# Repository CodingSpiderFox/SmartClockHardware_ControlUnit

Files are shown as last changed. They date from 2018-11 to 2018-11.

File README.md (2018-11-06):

# SmartClockHardware (ControlUnit)

This is part of the the hardware specification for my smart clock project.

The hardware consists of one device for the wake-up light functionality and another for the controls and LCD display.

The control unit with the display again, consists of 3 major parts held in one encasing

1.1) The controller for the input devices: various buttons and a PIR motion sensor.
There are many buttons for quite a lot of different features. As the NodeMCU doesn't have enough pins, two PCF8574 IO expander chips are used (yes, I tried the MCP23017 but didn't like the libraries and didn't want to write a new one).

1.2) The Mega2560 devboard with a 2.8" touch display shield on it and the two other parts (1.1 and 1.3) connected via hardware serials.

1.3) The NodeMCU controlling the illuminated button's lights.
Two buttons have RGB leds in the which can be controlled separately.
The other 9 buttons have single colour LEDs. All of the button's LEDs can be adjusted to different brightness levels, together with the LCD panel's backlight brightness.

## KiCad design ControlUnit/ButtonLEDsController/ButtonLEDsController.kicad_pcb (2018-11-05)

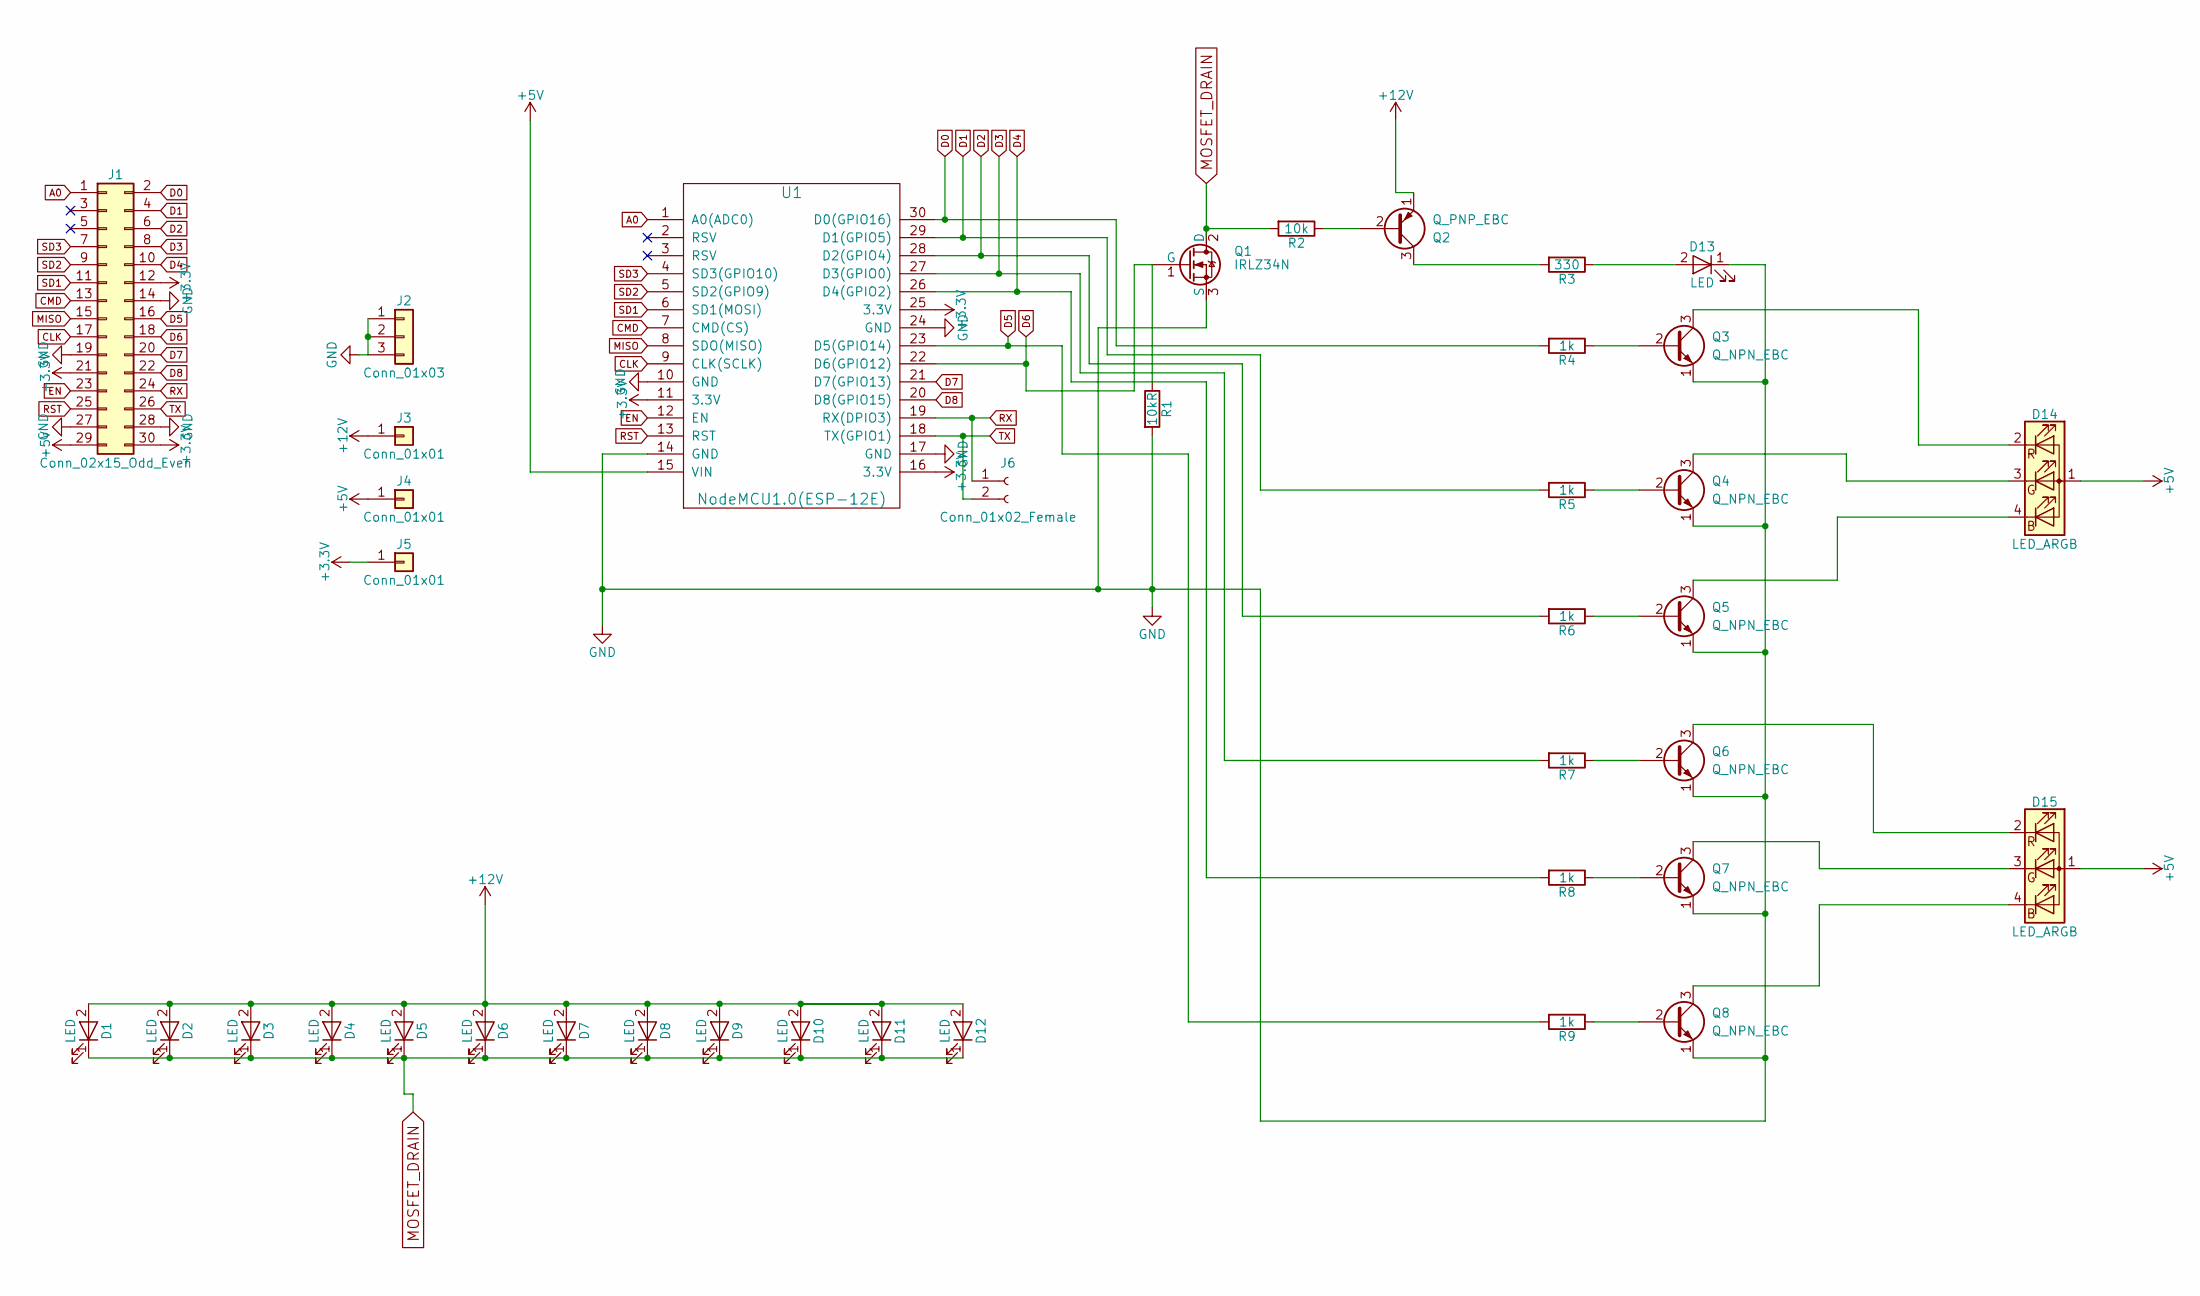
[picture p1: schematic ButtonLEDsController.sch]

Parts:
D1, D2, D3, D4, D5, D6, D7, D8, D9, D10, D11, D12, D13: LED; LED_D5.0mm
D14, D15: LED_ARGB; Pin_Header_Straight_1x04
J1: Conn_02x15_Odd_Even; Pin_Header_Straight_2x15_Pitch2.54mm
J2: Conn_01x03; Pin_Header_Straight_1x03_Pitch2.54mm
J3, J4, J5: Conn_01x01; Pin_Header_Straight_1x01_Pitch2.54mm
J6: Conn_01x02_Female; Socket_Strip_Straight_1x02_Pitch2.54mm
Q1: IRLZ34N; TO-220
Q2: Q_PNP_EBC; TO-92_Molded_Narrow
Q3, Q4, Q5, Q6, Q7, Q8: Q_NPN_EBC; TO-92_Molded_Narrow
R1: 10kR; R_Axial_DIN0204_L3.6mm_D1.6mm_P7.62mm_Horizontal
R2: 10k; R_Axial_DIN0204_L3.6mm_D1.6mm_P7.62mm_Horizontal
R3: 330; R_Axial_DIN0204_L3.6mm_D1.6mm_P7.62mm_Horizontal
R4, R5, R6, R7, R8, R9: 1k; R_Axial_DIN0204_L3.6mm_D1.6mm_P7.62mm_Horizontal
U1: NodeMCU1.0(ESP-12E); NodeMCU1.0(12-E)

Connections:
+3V3: J1.12, J1.21, J1.30, J5.1, U1.11 (3.3V), U1.16 (3.3V), U1.25 (3.3V)
+5V: D14.1 (A), D15.1 (A), J1.29, J4.1, U1.15 (VIN)
+12V: D1.2 (A), D2.2 (A), D3.2 (A), D4.2 (A), D5.2 (A), D6.2 (A), D7.2 (A), D8.2 (A), D9.2 (A), D10.2 (A), D11.2 (A), D12.2 (A), J3.1, Q2.1 (E)
A0: J1.1, U1.1 (A0(ADC0))
CLK: J1.17, U1.9 (CLK(SCLK))
CMD: J1.13, U1.7 (CMD(CS))
D0: J1.2, R4.2, U1.30 (D0(GPIO16))
D1: J1.4, R5.2, U1.29 (D1(GPIO5))
D2: J1.6, R6.2, U1.28 (D2(GPIO4))
D3: J1.8, R7.2, U1.27 (D3(GPIO0))
D4: J1.10, R8.2, U1.26 (D4(GPIO2))
D5: J1.16, R9.2, U1.23 (D5(GPIO14))
D6: J1.18, Q1.1 (G), R1.1, U1.22 (D6(GPIO12))
D7: J1.20, U1.21 (D7(GPIO13))
D8: J1.22, U1.20 (D8(GPIO15))
EN: J1.23, U1.12 (EN)
GND: D13.1 (K), J1.14, J1.19, J1.27, J1.28, J2.1, J2.2, J2.3, Q1.3 (S), Q3.1 (E), Q4.1 (E), Q5.1 (E), Q6.1 (E), Q7.1 (E), Q8.1 (E), R1.2, U1.10 (GND), U1.14 (GND), U1.17 (GND), U1.24 (GND)
MISO: J1.15, U1.8 (SDO(MISO))
MOSFET_DRAIN: D1.1 (K), D2.1 (K), D3.1 (K), D4.1 (K), D5.1 (K), D6.1 (K), D7.1 (K), D8.1 (K), D9.1 (K), D10.1 (K), D11.1 (K), D12.1 (K), Q1.2 (D), R2.2
unnamed: D13.2 (A), R3.1
unnamed: D14.2 (RK), Q3.3 (C)
unnamed: D14.3 (GK), Q4.3 (C)
unnamed: D14.4 (BK), Q5.3 (C)
unnamed: D15.2 (RK), Q6.3 (C)
unnamed: D15.3 (GK), Q7.3 (C)
unnamed: D15.4 (BK), Q8.3 (C)
unnamed: Q2.2 (B), R2.1
unnamed: Q2.3 (C), R3.2
unnamed: Q3.2 (B), R4.1
unnamed: Q4.2 (B), R5.1
unnamed: Q5.2 (B), R6.1
unnamed: Q6.2 (B), R7.1
unnamed: Q7.2 (B), R8.1
unnamed: Q8.2 (B), R9.1
RST: J1.25, U1.13 (RST)
RX: J1.24, J6.1, U1.19 (RX(DPIO3))
SD1: J1.11, U1.6 (SD1(MOSI))
SD2: J1.9, U1.5 (SD2(GPIO9))
SD3: J1.7, U1.4 (SD3(GPIO10))
TX: J1.26, J6.2, U1.18 (TX(GPIO1))

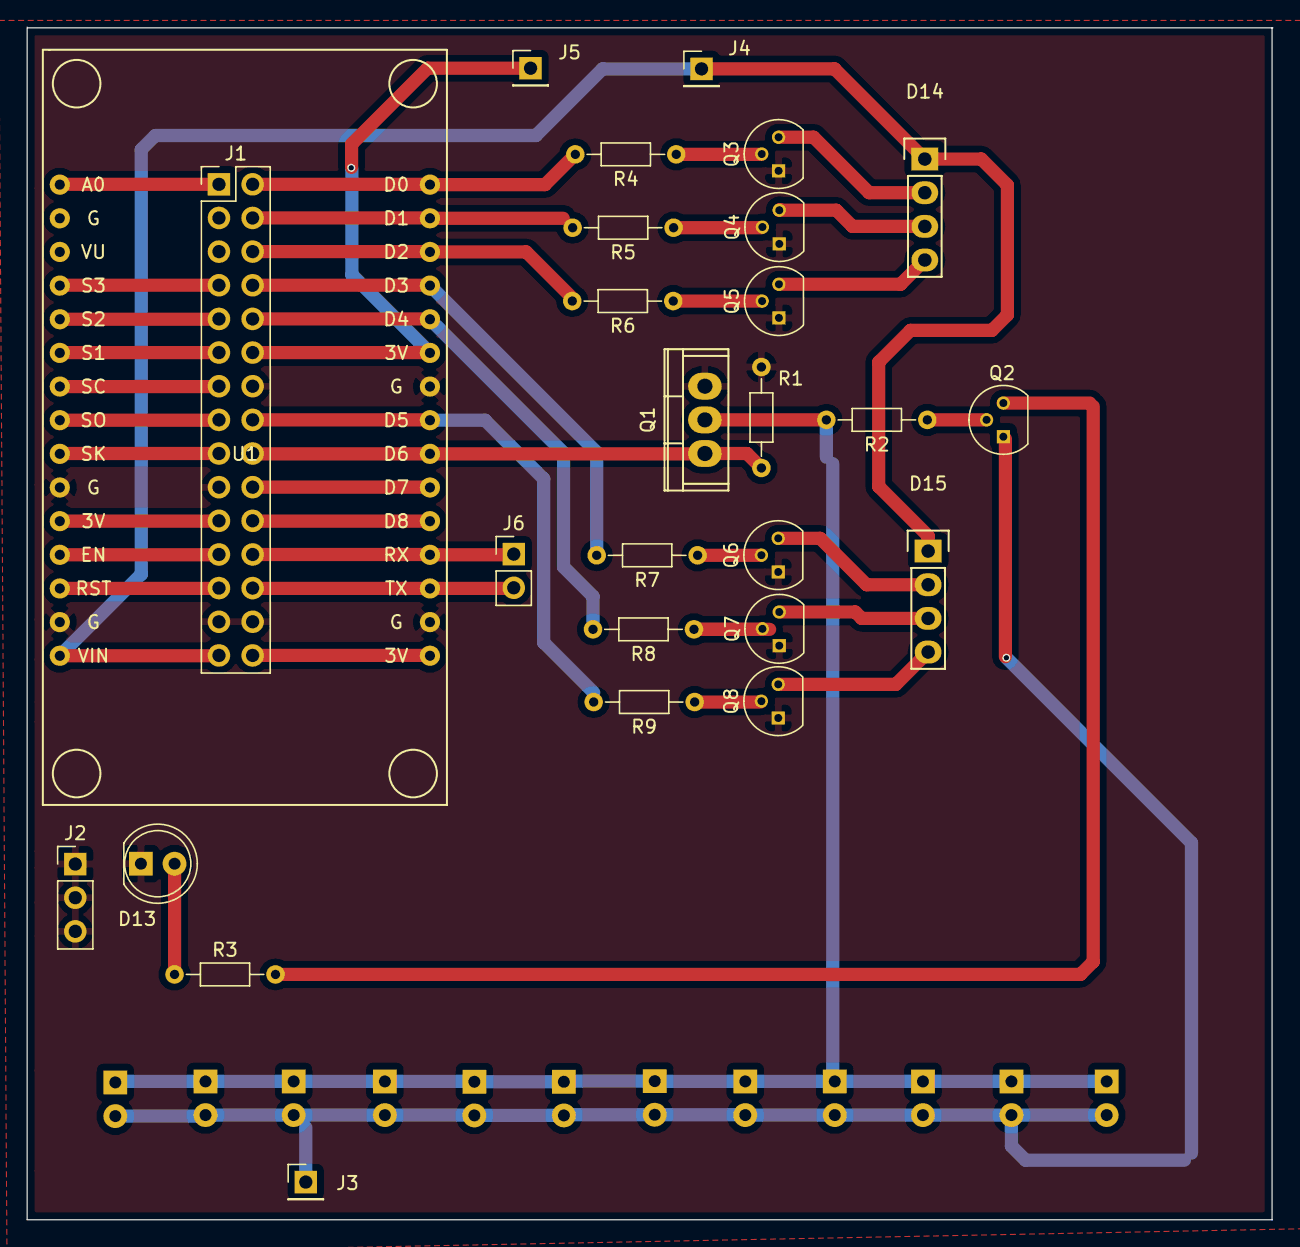
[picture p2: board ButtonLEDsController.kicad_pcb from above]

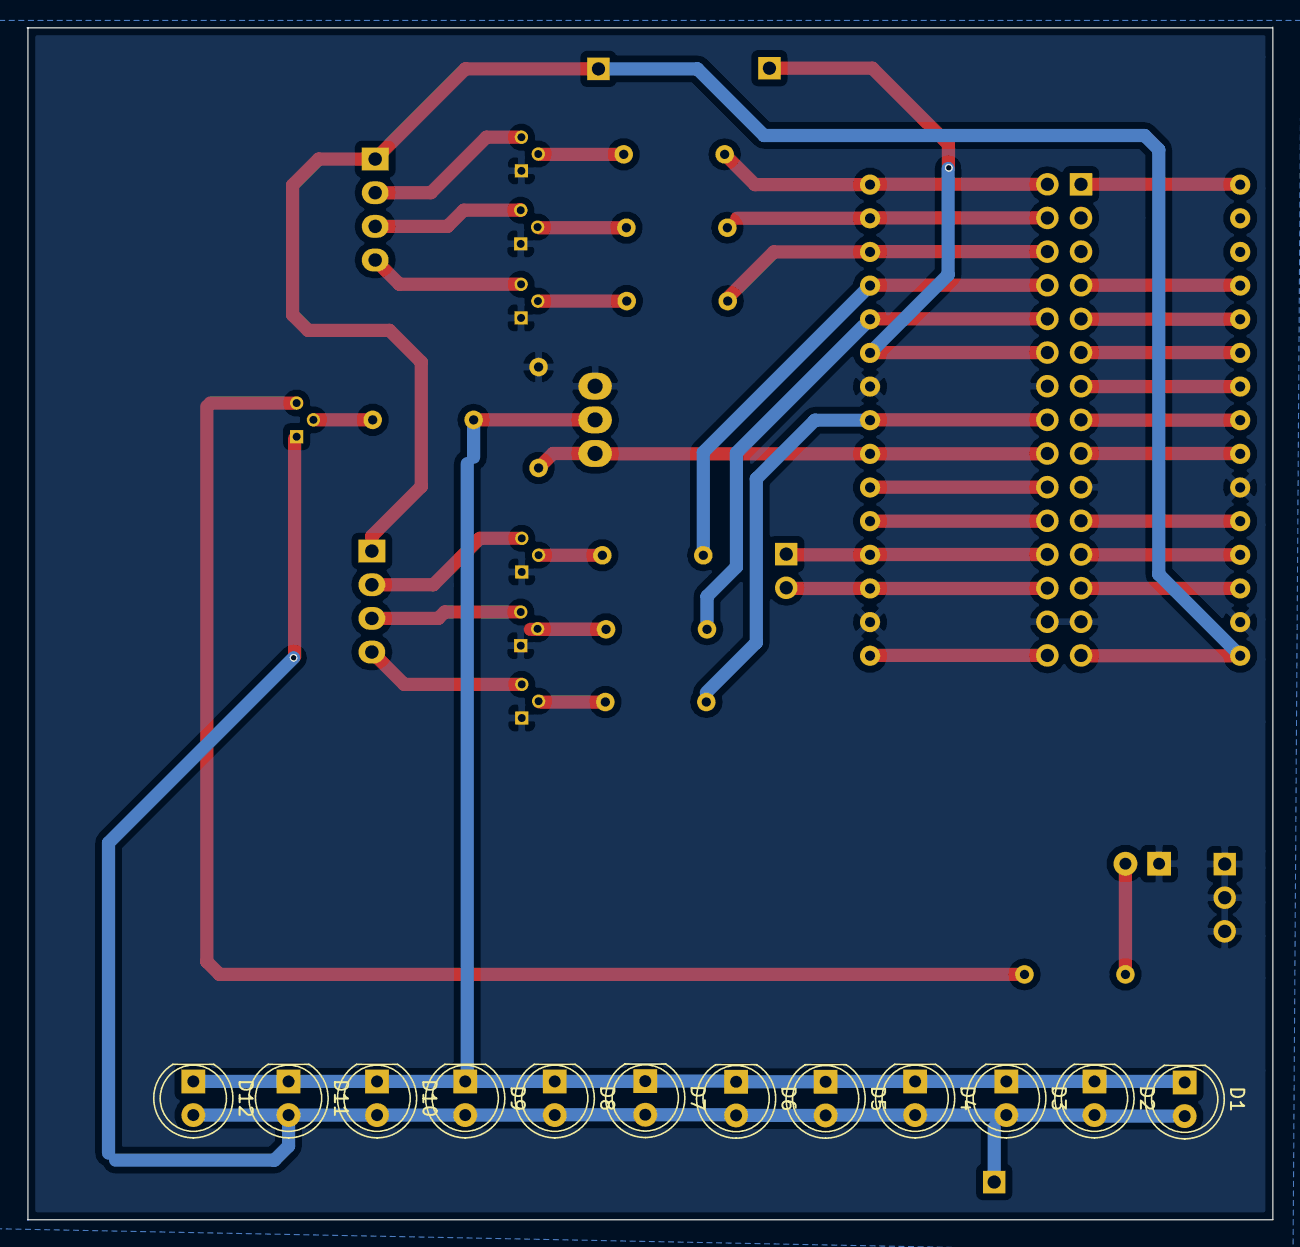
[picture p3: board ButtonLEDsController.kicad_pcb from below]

Board: 2 copper layers, 94.0 x 90.0 mm, 39 parts (12 on the bottom side), 40 nets.

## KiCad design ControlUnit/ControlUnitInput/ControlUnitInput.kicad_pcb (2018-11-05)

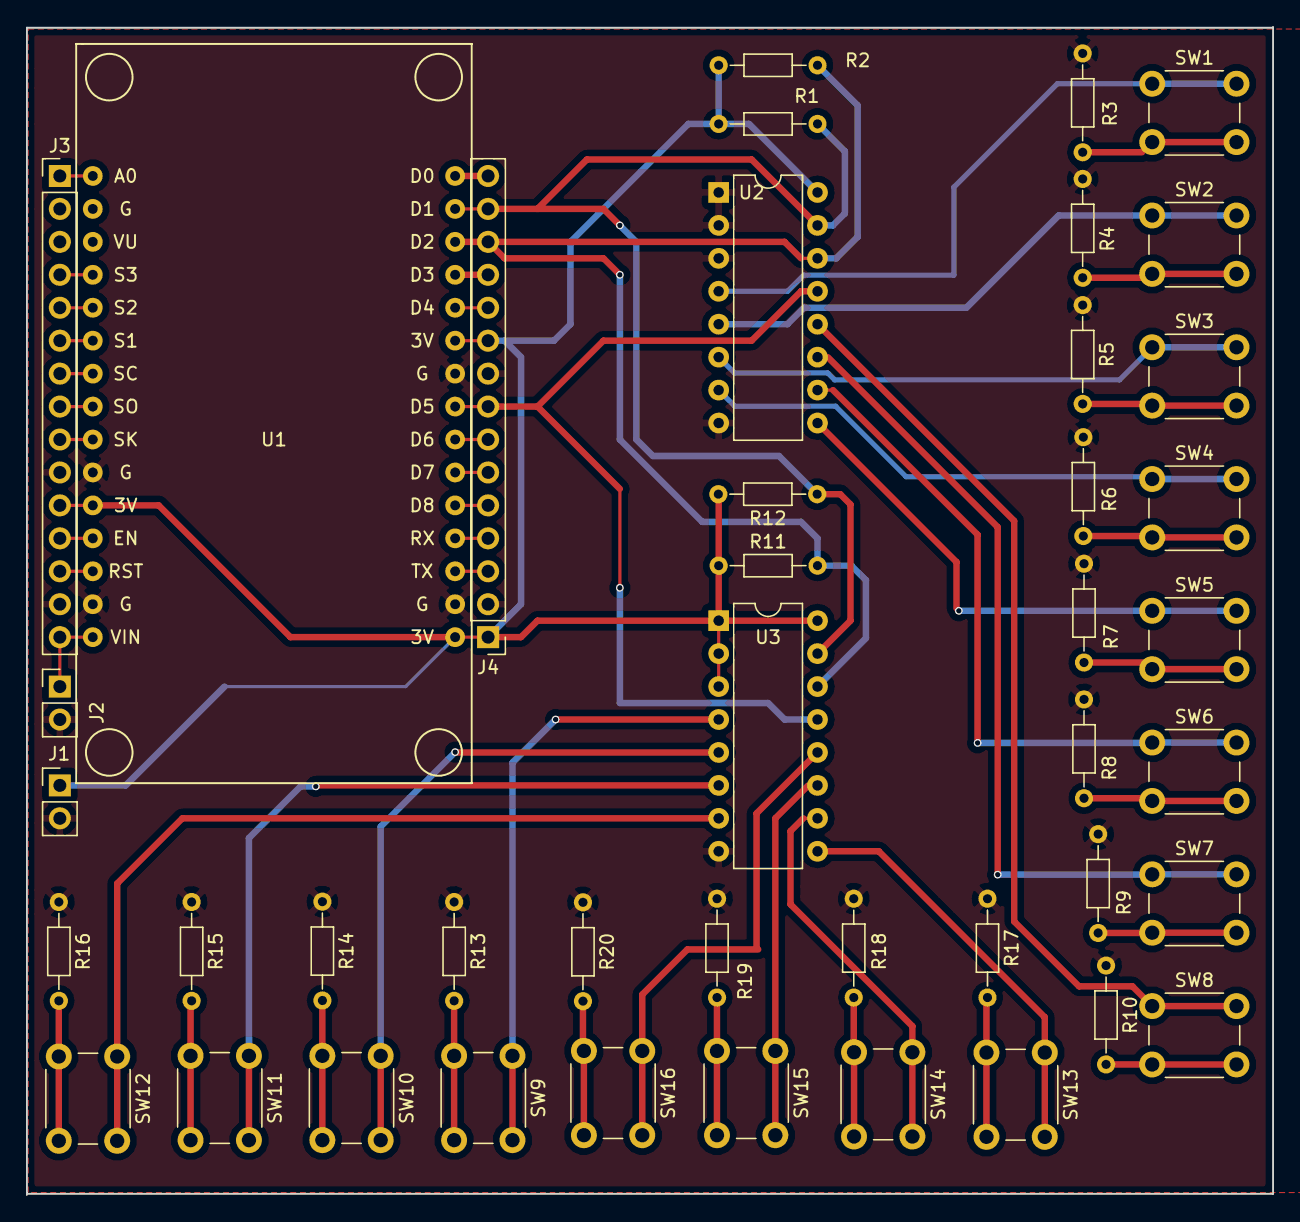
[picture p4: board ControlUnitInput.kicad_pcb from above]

Board: 2 copper layers, 96.1 x 90.1 mm, 43 parts (0 on the bottom side), 55 nets.

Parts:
J1, J2: Pin_Header_Straight_1x02_Pitch2.54mm
J3, J4: Pin_Header_Straight_1x15_Pitch2.54mm
R1, R2, R11, R12: 4.7k; R_Axial_DIN0204_L3.6mm_D1.6mm_P7.62mm_Horizontal
R3, R4, R5, R6, R7, R8, R9, R10, R13, R14, R15, R16, R17, R18, R19, R20: 10k; R_Axial_DIN0204_L3.6mm_D1.6mm_P7.62mm_Horizontal
SW1, SW2, SW3, SW4, SW5, SW6, SW7, SW8, SW9, SW10, SW11, SW13, SW14, SW15, SW16: SW_Push; SW_PUSH_6mm_h8mm
SW12: SW_PUSH_6mm_h8mm
U1: NodeMCU1.0(ESP-12E); NodeMCU1.0(12-E)
U2: DIP-16_W7.62mm
U3: PCF8574; DIP-16_W7.62mm

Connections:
+3V3: J1.1, J3.11, J4.1, J4.10, R1.2, R2.1, R11.1, R12.2, U1.11, U1.16, U1.25, U2.16, U3.1, U3.2, U3.3, U3.16
+5V: J2.1, J3.15, U1.15
A0: J3.1, U1.1
CLK: J3.9, U1.9
CMD: J3.7, U1.7
D0: J4.15, U1.30
D3: J4.12, U1.27
D4: J4.11, U1.26
D6: J4.7, U1.22
D7: J4.6, U1.21
D8: J4.5, U1.20
EN: J3.12, U1.12
GND: J1.2, J2.2, J3.10, J3.14, J4.2, J4.9, R3.1, R4.1, R5.1, R6.1, R7.1, R8.1, R9.1, R10.1, R13.1, R14.1, R15.1, R16.1, R17.1, R18.1, R19.1, R20.1, U1.10, U1.14, U1.17, U1.24, U2.1, U2.2, U2.3, U2.8, U3.8
INT: J4.8, U1.23, U2.13, U3.13
MISO: J3.8, U1.8
MOSI: J3.6, U1.6
unnamed: R3.2, SW1.2
unnamed: R4.2, SW2.2
unnamed: R5.2, SW3.2
unnamed: R6.2, SW4.2
unnamed: R7.2, SW5.2
unnamed: R8.2, SW6.2
unnamed: R9.2, SW7.2
unnamed: R10.2, SW8.2
unnamed: R13.2, SW9.2
unnamed: R14.2, SW10.2
unnamed: R15.2, SW11.2
unnamed: R16.2, SW12.2
unnamed: R17.2, SW13.2
unnamed: R18.2, SW14.2
unnamed: R19.2, SW15.2
unnamed: R20.2, SW16.2
unnamed: SW1.1, U2.4
unnamed: SW2.1, U2.5
unnamed: SW3.1, U2.6
unnamed: SW4.1, U2.7
unnamed: SW5.1, U2.9
unnamed: SW6.1, U2.10
unnamed: SW7.1, U2.11
unnamed: SW8.1, U2.12
unnamed: SW9.1, U3.4
unnamed: SW10.1, U3.5
unnamed: SW11.1, U3.6
unnamed: SW12.1, U3.7
unnamed: SW13.1, U3.9
unnamed: SW14.1, U3.10
unnamed: SW15.1, U3.11
unnamed: SW16.1, U3.12
RST: J3.13, U1.13
RX: J4.4, U1.19
SCL: J4.13, R2.2, R11.2, U1.28, U2.14, U3.14
SD2: J3.5, U1.5
SD3: J3.4, U1.4
SDA: J4.14, R1.1, R12.1, U1.29, U2.15, U3.15
TX: J4.3, U1.18

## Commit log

2018-10-13 1mm thickness for all tacks
    [ButtonLEDsController.kicad_pcb]
2018-10-13 0.4 - 0.5 mm track thickness
    [ControlUnitInput.kicad_pcb]
2018-11-05 prepared to order pcbs
    [ButtonLEDsController-B.Cu.gbr, ButtonLEDsController-B.Mask.gbr, ButtonLEDsController-B.SilkS.gbr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]

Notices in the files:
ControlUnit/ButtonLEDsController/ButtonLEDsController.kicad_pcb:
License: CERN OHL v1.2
